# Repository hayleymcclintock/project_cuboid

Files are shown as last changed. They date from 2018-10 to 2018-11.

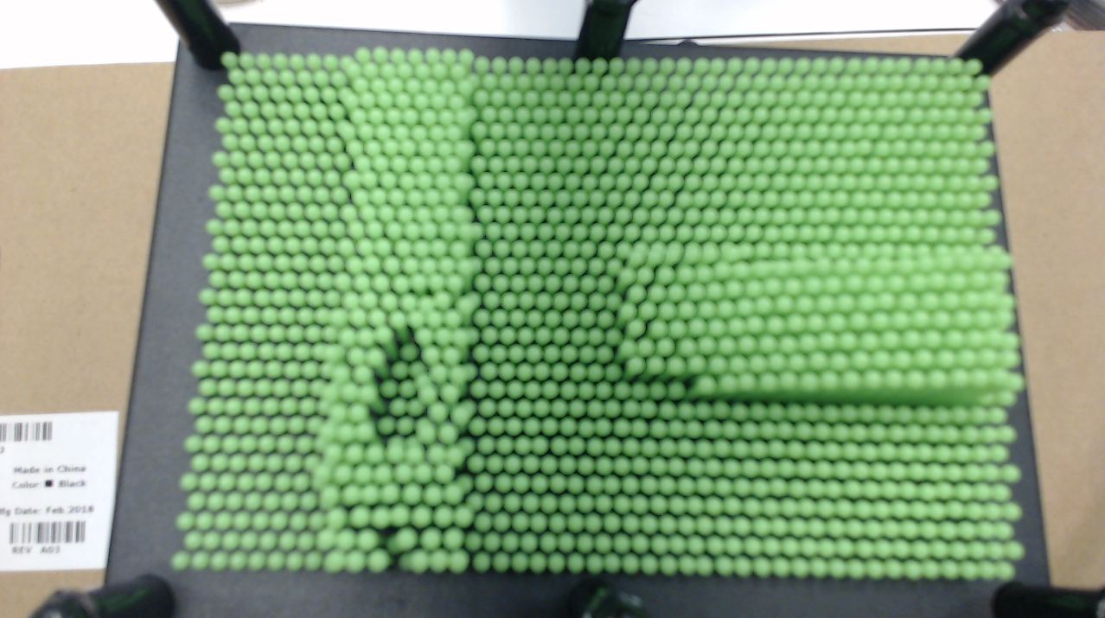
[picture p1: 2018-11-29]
Supplements/Presentations/1 First Checkin/Selection_001.png

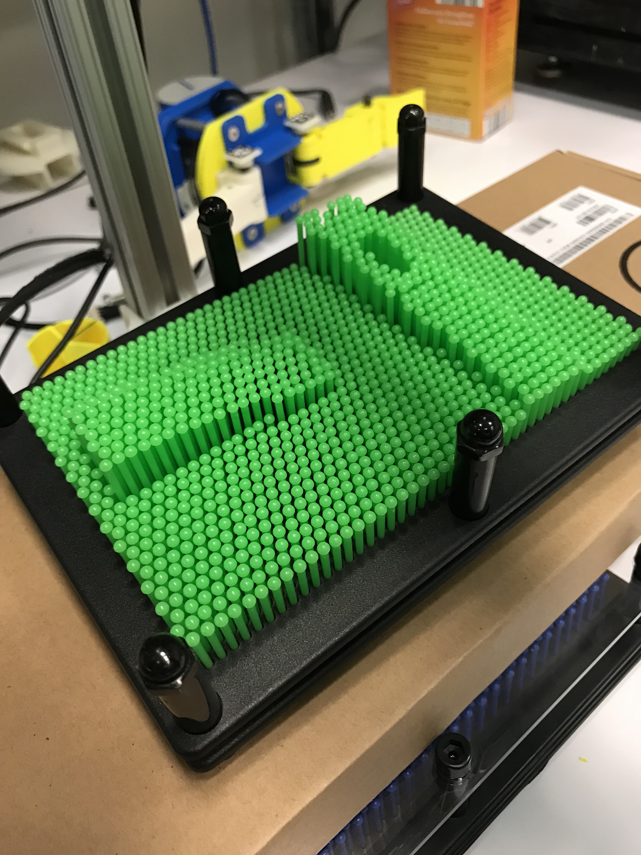
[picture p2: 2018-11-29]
Supplements/Presentations/1 First Checkin/ground_truth.jpg

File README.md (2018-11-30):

# PROJECT CUBOID
This repository contains the code and supplements to the cuboid locomoting and mapping robot for Intelligent Robotics Lab. In this repo, you will find the ROS code, paper, presentations, and data. In the following sections, we will talk about how you can get started with this project!

### Contributors
Andrew Morgan  
Robert Baines  
Hayley McClintock  

## System Requirements 
The code for this repository was mostly developed with/for ROS Kinetic (Ubuntu 16.04), with Python 2.7. OpenCV version 3.3.1-dev provides a stable bridge from OpenCV2 to OpenCV3, and was used for vision processing in this environment. If you try to run this package and have errors, please ensure you have a similar version. An Arduino Mega 256 microcontroller was utilized to control locomotion bladders and LED sequences. This communication was performed in Python and is fairly trivial with the pyserial interface. Please note that the Arduino code utilized is located within the ROS `hardware_coms` package, and is specific to the setup of this cuboid. LED addressing will need adjusted according to your specific unit.   

## ROS Packages
This section serves to introduce the reader to the packages involved in the ROS workspace. In general,the main packages are as follows:
### Vision Processor
This package takes in an image from the USB cam `topic: /camera/image_raw` and processes it accordingly. It will then publish the result according to desired block resolutions determined inside of the file (since we did not change this much, we stuck with 40 rows and 50 columns = 2000 data points).  

### USB Camera
Standard ROS camera package for working with and publishing an image from a webcam. Our main interest in this package is the use of  the`/camera/image_raw` published image. This is an open package for ROS that many people use. It is important to note that your camera does limit the resolution of this node. For the cameras used in this project, we were restricted to a `640 x 480` image, where typically you will work with 720p or 1080p. If you are requesting too high of a resolution, you will receive a camera error that eludes to improper communication. As of ubuntu 10, all drivers should be installed on your system upon setup, so therefore you need to change you camera resolution. 

### ROS Video Recorder 
Video Recorder node used for capturing published video channels in ROS. Specific parameter files must be set, allowing for multiple  videos to be recorded at the same time. To set these files, simply change data in the associated launch file in this package. In general, you will want your output and input video to be the same resolution (the package allows for users to record multiple streams at the same time, but we do not need that feature). 

### Master Control
This package will be used as the controller for all processes and timing for our system. This node communicates with the others, in a top down approach (as presented in the paper), to coordinate actuation, take pictures given specific lighting condiitions, and create the final map. You must run this node and tell it to start. Upon starting, it will complete the following sequence:  

```python
SIDE = 1
while True:
  flipCuboid()
  for edge in sideEdges:
    lightUpSequence(Edge)
    s = takePicture()
    out = processData(s)
    save(out)
  SIDE=SIDE+1
  SIDE = (SIDE-1)%4+1  #Sides are 1-4

```
## Running the Code
To get started, you will need the requirements specified in the previous section. After completing this task, you can launch the main cuboid program by:  
``roslaunch master_controller cuboid.launch``
After the system is up and running, you will need to enable movement and data collection by calling the roservice:  
``rosservice call /master_controller/enable_collection "data= true"``  
  
A useful tool for debugging is by running:  
`roslaunch hardware_coms hardware_coms_std.launch`  
This will allow you to interract with the arduino and send individual commands to the cuboid (turn on/off lights, inflate/deflate bladders). Please follow the integer values specifies in `ROS_ws/src/hardware_coms/Arduino Code/Arduino Communication.xlsx`. For example, if you wanted to inflate the bladders for the third face,  
``rosservice call /hardware_coms/do_something "data=3"``  
or if you would like to light up edge 3 of the second face,  
``rosservice call /hardware_coms/do_something "data=23"``  

## Contributions  

### Robert Baines  

### Hayley McClintock  

### Andrew Morgan
In this work, Andy was responsible for all ROS programming of the cuboid, of which is provided in the catkin workspace. This work has been sufficiently documented inside of the files so that others can properly understand and recreate this project. In addition to this duty, Andy worked on properly calibrating the camera and ensuring the vision extraction algorithm was sufficient for the shapes by shades approach. This included spec'ing a camera, calibrating the LEDs with different colors/sequences, and installing this on the cuboid.

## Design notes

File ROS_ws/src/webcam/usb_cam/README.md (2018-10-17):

usb_cam 
=======

#### A ROS Driver for V4L USB Cameras
This package is based off of V4L devices specifically instead of just UVC.

For full documentation, see [the ROS wiki](http://ros.org/wiki/usb_cam).

[Doxygen](http://docs.ros.org/indigo/api/usb_cam/html/) files can be found on the ROS wiki.

### License
usb_cam is released with a BSD license. For full terms and conditions, see the [LICENSE](LICENSE) file.

### Authors
See the [AUTHORS](AUTHORS.md) file for a full list of contributors.

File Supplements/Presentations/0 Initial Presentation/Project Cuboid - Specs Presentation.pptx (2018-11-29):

## Project Cuboid

Robert Baines, Andrew Morgan, Hayley McClintock

## Problem Statement

A cuboid with a dynamic contact surface for adaptable motion and topographic mapping on variable terrains.

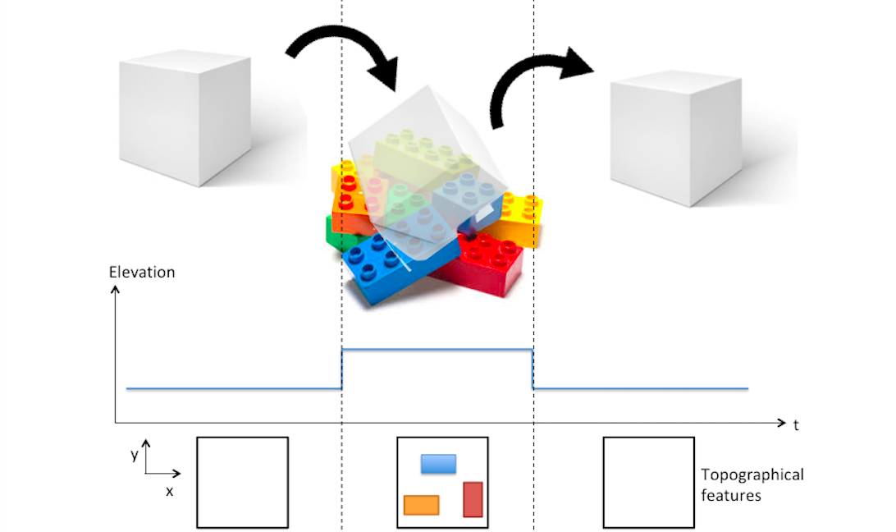
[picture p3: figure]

## Approach

- Construct a cube where 4 faces contain an array of solenoids (or other actuators)
  - Solenoids actuate the cube and serve as sensing elements
- Soft skin wrapped around the outside to prevent debris from interfering with solenoids in addition to providing better surface for rolling
- Incorporation of pressure sensors elastically coupled to solenoids for mapping the environment

## Evaluation

- Cuboid will “roll” over an obstacle course
  - Make a topographical map based on sensor feedback
  - Successfully overcome various elevation obstacles
  - Obstacles may include but are not limited to:
    - Legos
    - Office supplies (pens,paperclips, etc.)
- Quality metrics:
  - Euclidean error based on ground truth

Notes: Interesting to see the resolution we can get out of the pressure sensors

## Deliverables

- 10/12
  - Order initial testing components
  - CAD model and design
  - Electronic architecture diagram
  - Complete solenoid testing
- 11/2
  - Prototype I constructed
  - Sensor calibration
  - Testing plan
- 12/3
  - Final cube finished
  - Achieve topographical mapping
  - Locomote over obstacle course

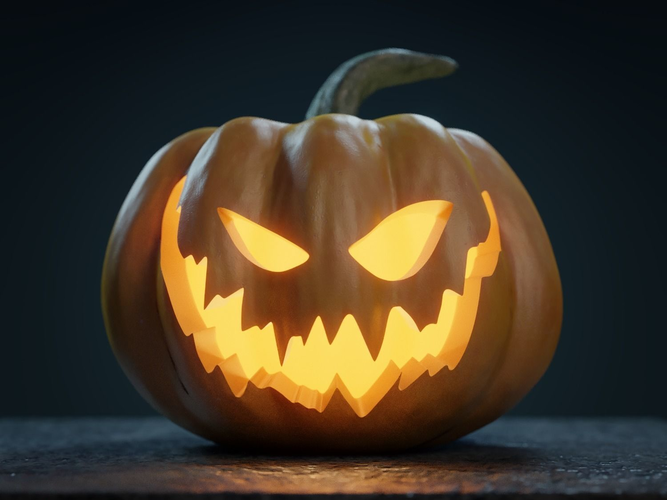
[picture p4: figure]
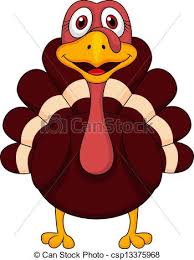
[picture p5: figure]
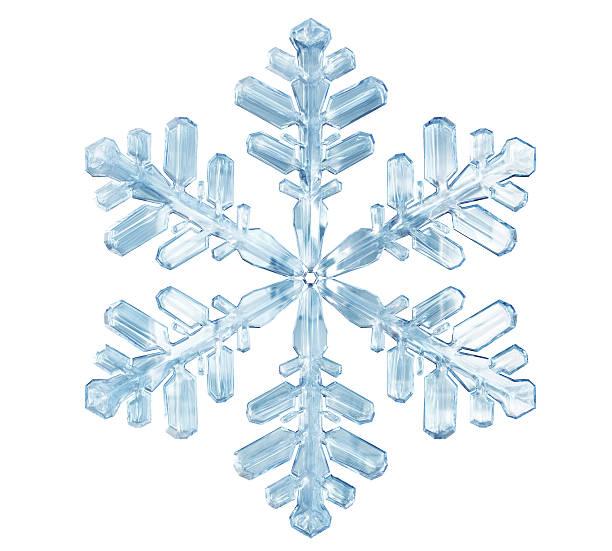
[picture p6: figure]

## Resources

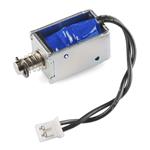
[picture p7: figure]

- Solenoids (20 at $7.99 each)
- Arduino or other microcontroller with peripherals
  - Megan 2560 for required number of inputs
- Relay arrays (25 at $2 each)
  - Reduction to 5 if desired
- IMU ($20)
  - Prior calibration required
  - Key component to sensing acceleration based on actuation input
- Pressure sensors (25 at $8 each)

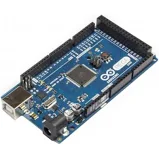
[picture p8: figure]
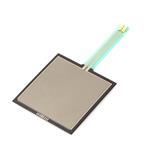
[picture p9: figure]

## Cubes in the literature

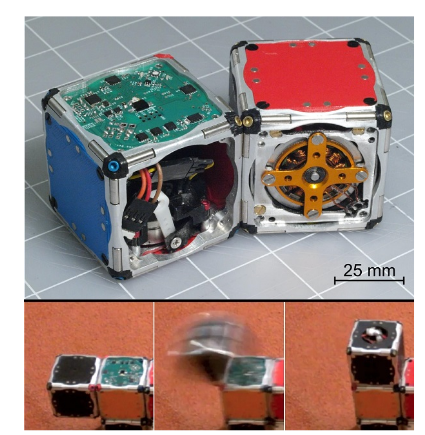
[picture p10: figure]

[Romanishin et al.]

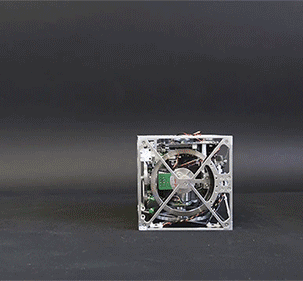
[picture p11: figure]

[Gajamohan et al.]

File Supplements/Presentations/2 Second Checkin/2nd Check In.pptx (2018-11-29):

## Project Cuboid

Robert Baines, Andrew Morgan, Hayley McClintock

## Problem Statement

A cuboid with a dynamic contact surface for adaptable motion and topographic mapping on variable terrains.


## Deliverables

- 10/12
  - Order initial testing components
  - CAD model and design
  - Electronic architecture diagram
  - Complete solenoid testing
- 11/2
  - Prototype I constructed
  - Sensor calibration
  - Testing plan
- 12/3
  - Final cube finished
  - Achieve topographical mapping
  - Locomote over obstacle course


## What we have done

- Prototype I in progress (show it)
- ROS master architecture done (show it next slide)
  - Catkin_ws: https://github.com/asmorgan24/project_cuboid
- Vision detection algorithm done
- Figured out appropriate lighting geometry for shapes by shades
  - Symmetric on/off average of 4 sides of square
- Arduino pressure regulator test code working
  - Bang bang controller ros node in progress
- Testing plan:
  - Fixed obstacle course on table top: measured object heights and dimensions
  - Evaluation metric: average mean squared error for each “plot” measurement over course
- IEEE format Manuscript started

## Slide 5

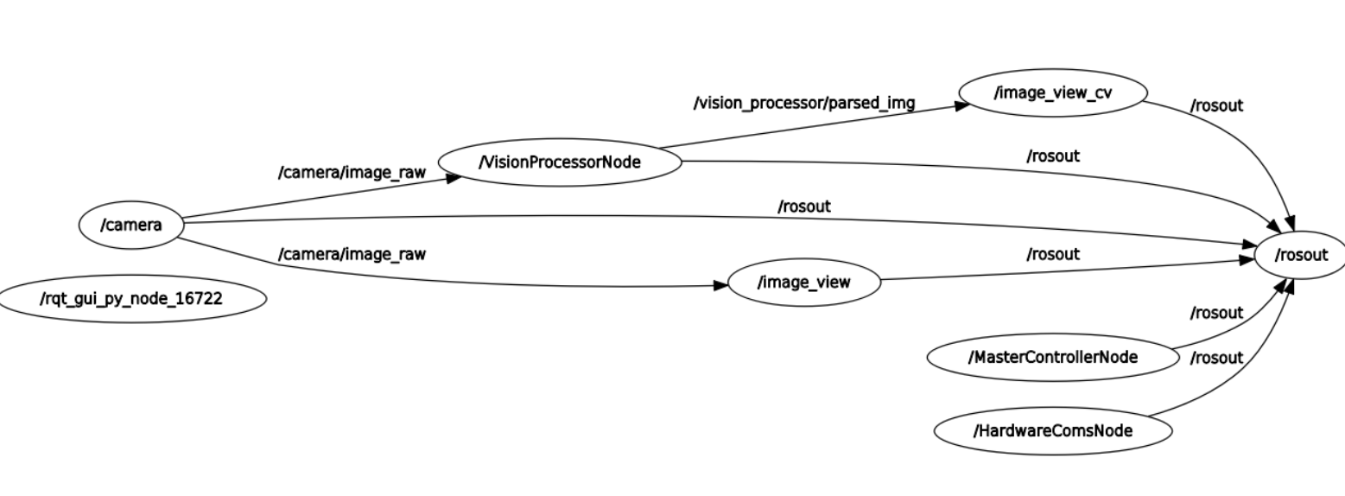
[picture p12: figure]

## Problems

- Rolling the cube
  - Inflate balloon bends in the wrong direction under the weight of the cube
  - Pins seem to inhibit motion
- Pins on pin art toy are poor quality
- We anticipate on running into larger problems with the full prototype

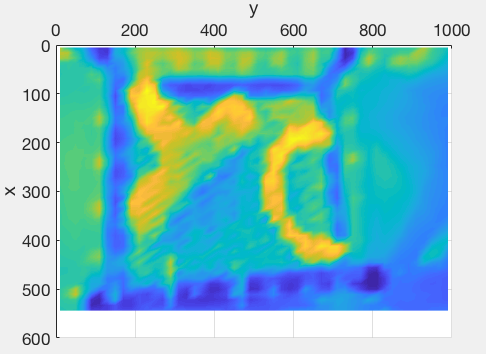
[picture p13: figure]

LED array appears in
Field of view. Easy fix via crop

## Next steps

- Get actuation working
- Finish a full prototype
- Test cameras and lighting
- Prototype camera mounting system
- Create wiki page and start populating
  - Where do we make a wiki page?

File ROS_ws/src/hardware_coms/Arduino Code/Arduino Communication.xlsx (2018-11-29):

 | Serial ASCII byte out from ROS |  | Arduino Example
Pressures | ON | OFF | https://www.arduino.cc/en/Tutorial/SerialEvent
1 | 1 | 5
2 | 2 | 6
3 | 3 | 7
4 | 4 | 8
LED Lights
Side 1
1 | 11 | 15
2 | 12 | 16
3 | 13 | 17
4 | 14 | 18
Side 2
1 | 21 | 25
2 | 22 | 26
3 | 23 | 27
4 | 24 | 28
Side 3
1 | 31 | 35
2 | 32 | 36
3 | 33 | 37
4 | 34 | 38
Side 4
1 | 41 | 45
2 | 42 | 46
3 | 43 | 47
4 | 44 | 48

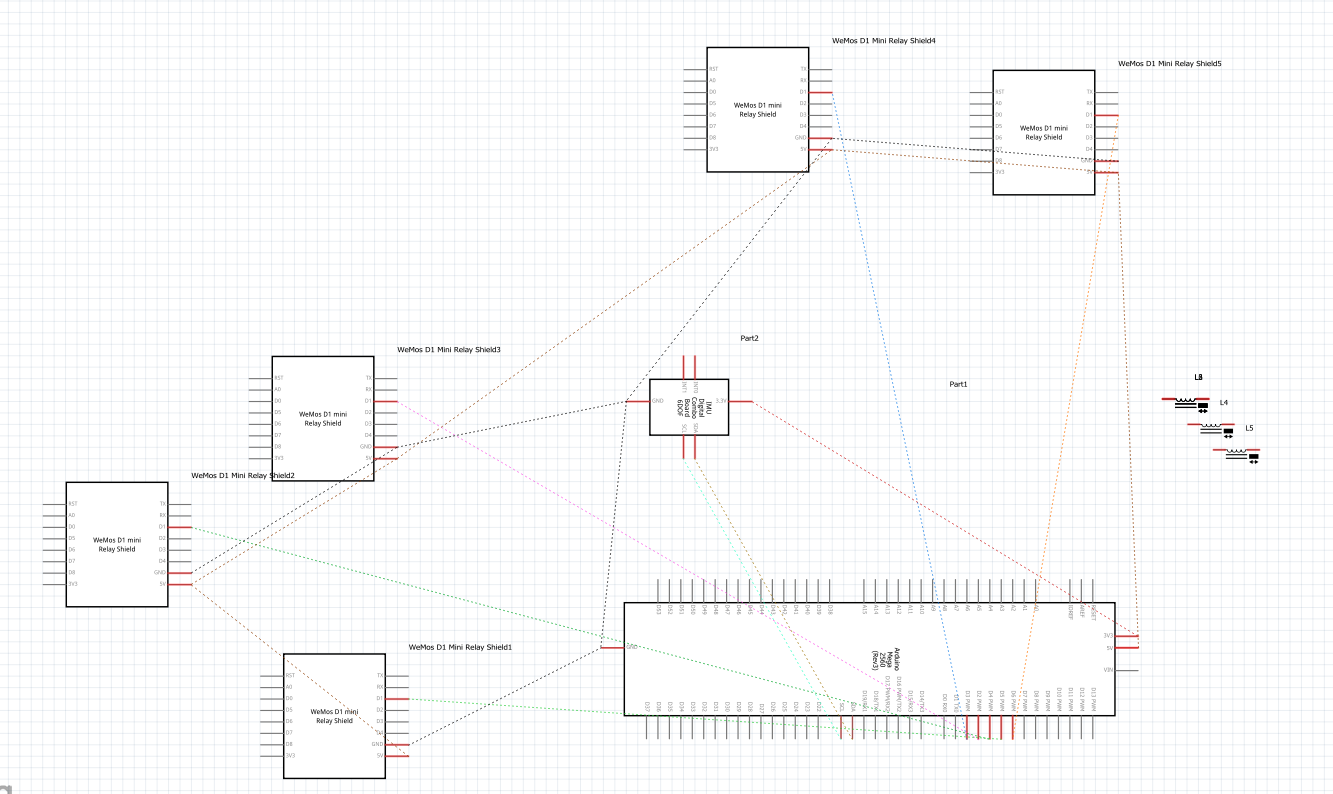
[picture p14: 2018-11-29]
Supplements/Presentations/2 Second Checkin/Initial Schematic/v1_schem.PNG

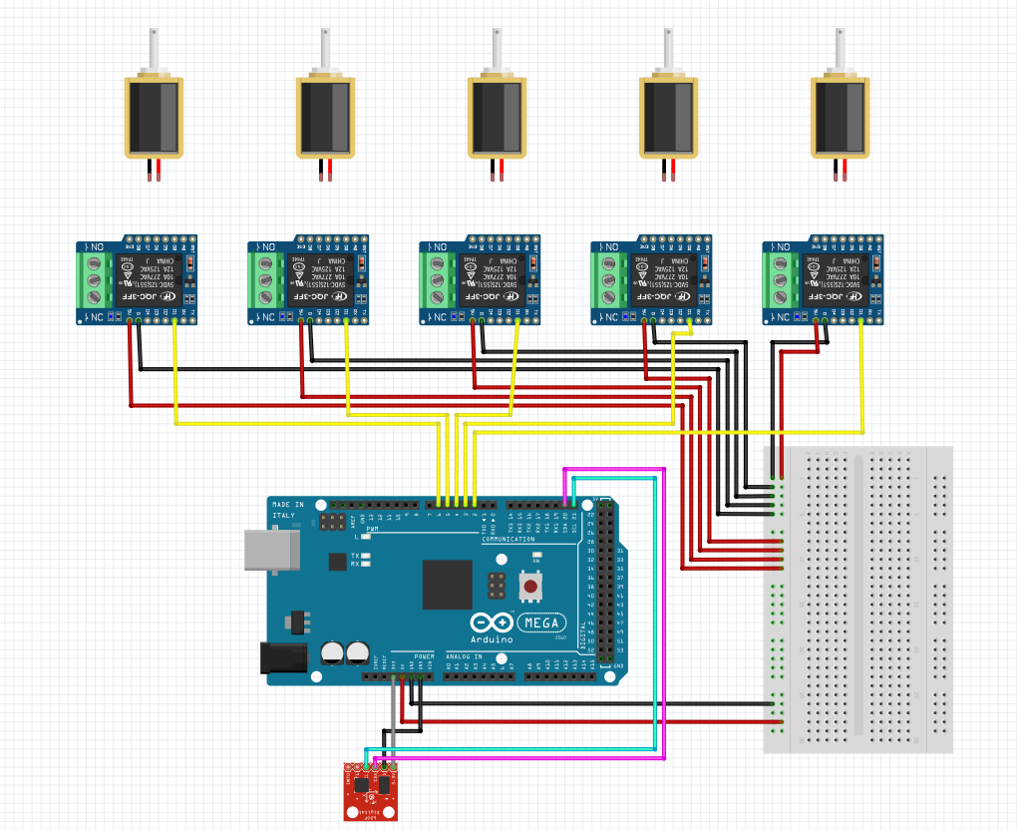
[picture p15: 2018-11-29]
Supplements/Presentations/2 Second Checkin/Initial Schematic/v1.PNG

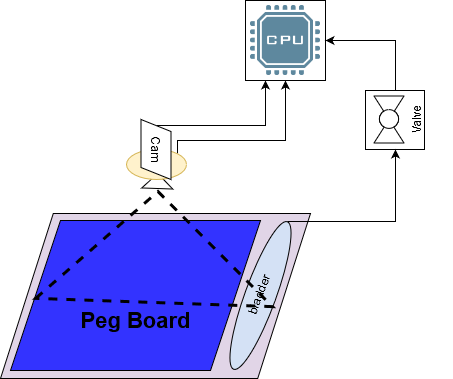
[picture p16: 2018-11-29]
Supplements/Presentations/2 Second Checkin/3 Deliverable 1 Schematic/Diagram1.png

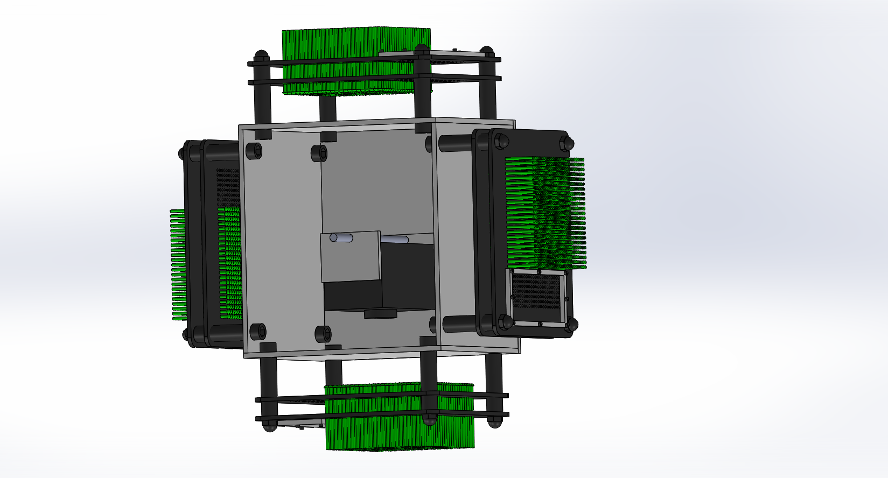
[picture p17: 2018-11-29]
Supplements/Presentations/1 First Checkin/cuboid.png

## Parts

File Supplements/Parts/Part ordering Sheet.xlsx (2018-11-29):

COMPLETED ORDERS
Item | Cost | URL | Quantity | Why | Total
Resistive pressure sensor | 9.95 | https://www.mouser.com/ProductDetail/SparkFun/SEN-09376?qs=WyAARYrbSnZm3k2OB4XwnA%3D%3D | 2 | test | 19.9
velostat conductive sheet | 3.95 | https://www.adafruit.com/product/1361?gclid=EAIaIQobChMIh9S61vPY3QIVmFYNCh0UEQNpEAQYAyABEgJq2vD_BwE | 3 | test | 11.85
5v mico solenoid | 7.99 | https://www.amazon.com/Electromagnet-Solenoid-Spring-Cabinet-Special/dp/B075H5WDD1?s=industrial | 3 | test | 23.97
5v mini push solenoid | 4.95 | https://www.adafruit.com/product/2776 | 3 | test | 14.85
bigger solidenoid | 12.93 | https://www.amazon.com/Uxcell-a14032200ux0084-Electric-Electromagnet-Solenoid/dp/B00LBQ229Y | 2 | test solenodi | 25.86
IMU | 4.39 | https://www.amazon.com/MPU-6050-MPU6050-Accelerometer-Gyroscope-Converter/dp/B008BOPN40 | 1 | test | 4.39
IMU | 8.49 | https://www.amazon.com/HiLetgo-Gyroscope-Acceleration-Accelerator-Magnetometer/dp/B01I1J0Z7Y | 1 | test | 8.49
pin art toy | 6.99 | https://www.amazon.com/Adorox-Plastic-Novelty-Multiple-Colors/dp/B00P6S4W0U?s=toys-and-games | 1 | sensor probe test | 6.99
pin art toy 2 | 10.99 | https://www.amazon.com/ScienceGeek-Plastic-Sculpture-Novelty-Green/dp/B01HBH4GTK | 1 | sensor probe test | 10.99 | TOTAL SPENT | $263.78
pin art toy 3 | 12.69 | https://www.amazon.com/LifeEase-Imagination-Challenge-Innovative-Instant-Changing/dp/B07BRS6KCM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 | 1 | sensor probe test | 12.69
4x5'' pin art toy, green | 8.99 | https://www.amazon.com/gp/product/B00S8LME9I | 1 | cause | 8.99 |  |  |  |  | 10/2/18: spring parts order
4x5'' pin art toy, blue | 5.1 | https://www.amazon.com/Shape-Child-Educational-Novelty-Table/dp/B01BFVNHVG?s=Toys+%26+Games | 1 | cause | 5.1
4x5'' pin art toy, red | 7.99 | https://www.amazon.com/Adorox-Plastic-Novelty-Multiple-Colors/dp/B0743MC8WK | 1 | cause | 7.99 |  |  |  |  | spring (k = 7 lbs./in.) | 4.85 | https://www.mcmaster.com/9434K25 | 1 | test | 4.85
3.5''x5'' metal pin art toy | $8.09 | https://www.amazon.com/Toysmith-Black-Frame-3-75-Inch-5-Inch/dp/B000FN2FI2 | 1 | test metal pins | $8.09 |  |  |  |  | spring (k = 1.1 lbs./in.) | 6.28 | https://www.mcmaster.com/9657K412 | 1 | test | 6.28
12V led white strip | $7.99 | https://www.amazon.com/Flexible-Daylight-Kitchen-Christmas-Non-waterproof/dp/B00HSF65MC | 1 | test leds | $7.99 |  |  |  |  | spring (k = 5 lbs./in.) | 4.85 | https://www.mcmaster.com/9434K38 | 1 | test | 4.85
LED assortment | $9.99 | https://www.amazon.com/Lights-Emitting-Assortment-Arduino-300-Pack/dp/B00UWBJM0Q | 1 | test leds | $9.99 |  |  |  |  | spring (k = 3 lbs./in.) | 4.98 | https://www.mcmaster.com/9434K53 | 1 | test | 4.98
RGB Led | $8.96 | https://www.amazon.com/Tricolor-Multicolor-Lighting-Electronics-Components/dp/B01C19ENDM | 1 | test leds | $8.96 |  |  |  |  | spring (k = 4.5lb/in) | 4.85 | https://www.mcmaster.com/9434K52
16ft white led strip | $1.66 | https://www.amazon.com/Radiance-Flexible-Daylight-Cuttable-Linkable/dp/B01J0WD7M6 | 1 | test leds | $1.66 |  |  |  |  | spring (k = 5 lbs./in.) | 4.85 | https://www.mcmaster.com/9434K163
addressable LED | $26.95 | https://www.amazon.com/NooElec-Addressable-Waterproof-Connectors-Pre-Soldered/dp/B008F05N54 | 1 | addressable LEd | $26.95
120 degree webcam | 29.99 | https://www.amazon.com/ELP-megapixel-Camera-Module-120degree/dp/B01DRJXDEA | 1 | Vision | 29.99
addressable LED | $26.95 | https://www.amazon.com/NooElec-Addressable-Waterproof-Connectors-Pre-Soldered/dp/B008F05N54 | 4 | addressable LEd
 | total
 | 255.69
PENDING ORDERS
Item | Cost | URL | Quantity | Why | Total
pin art toy 3 | 12.69 | https://www.amazon.com/LifeEase-Imagination-Challenge-Innovative-Instant-Changing/dp/B07BRS6KCM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 | 2 | extra pins | 25.38
Magnetic tape | 14.99 | https://www.amazon.com/Gimars-Anisotropic-Strong-Magnetic-Adhesive/dp/B07C3MQ86M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 | 1 | mounting | 14.99
 |  |  |  |  |  |  | 90 degree webcam | 48 | https://www.amazon.com/Spinel-Non-distortion-1920x1080-Adjustable-UC20MPB_ND/dp/B07143BJ6J | 1 | Vision | 48

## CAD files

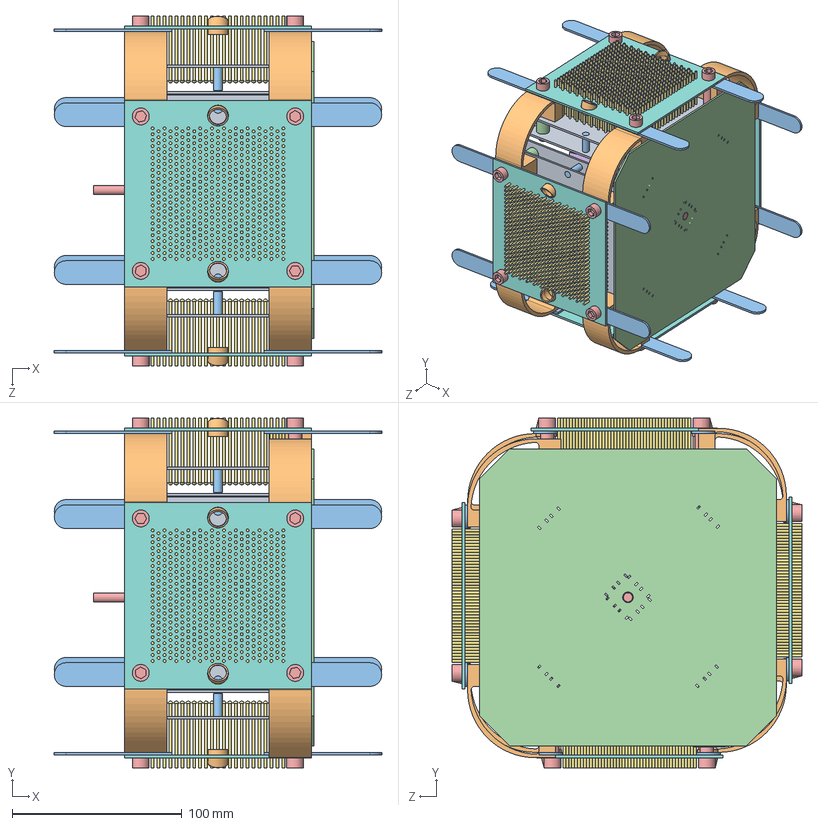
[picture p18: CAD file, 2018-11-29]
Supplements/Parts/CAD/total_assem.SLDASM
193.0 x 206.2 x 206.2 mm
top plate x 4
bracket x 8
popsicle stick x 16
spacer x 16
thick pin x 16
spacer cap x 16
thin pin x 2072
balloon side x 4
led side x 4
director x 8
dowel x 16
trimmed side
long_dowel
cuboid_camera

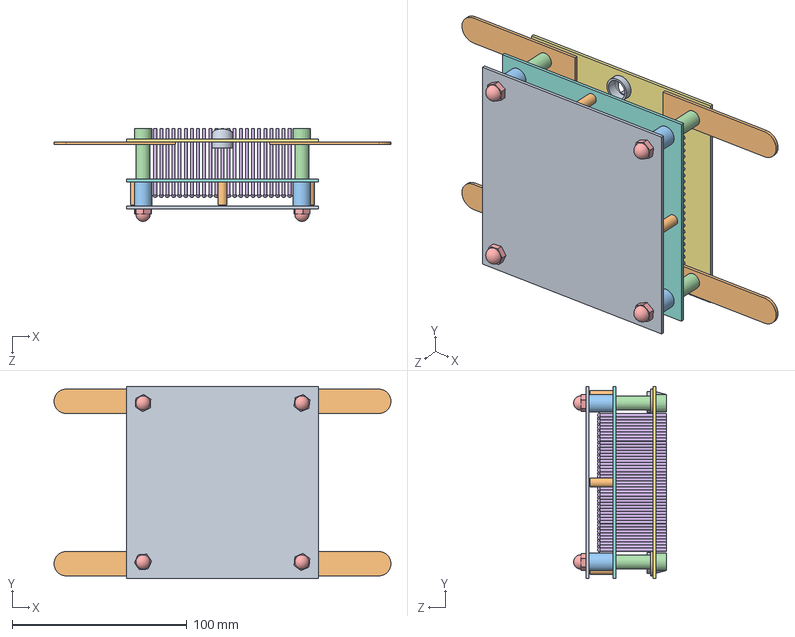
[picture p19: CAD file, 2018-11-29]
Supplements/Parts/CAD/Assem1_no_brackets.SLDASM
193.0 x 110.0 x 53.2 mm
top plate
popsicle stick x 4
spacer x 4
thick pin x 4
spacer cap x 4
thin pin x 518
balloon side
led side
director x 2
dowel x 4

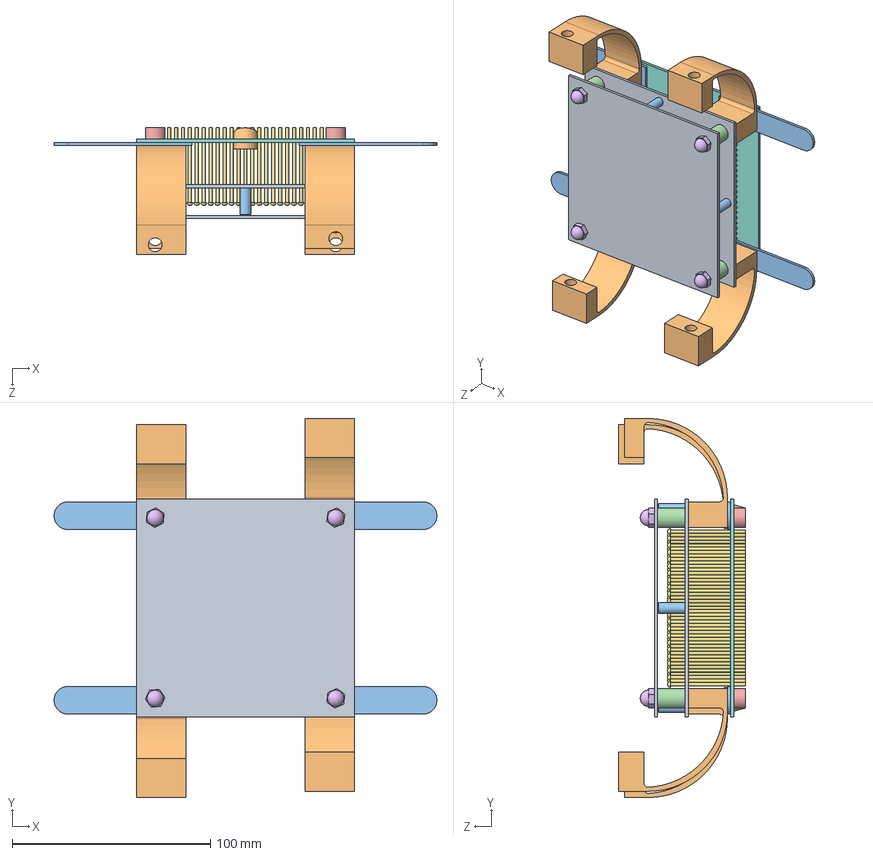
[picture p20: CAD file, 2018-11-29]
Supplements/Parts/CAD/Assem1.SLDASM
193.0 x 191.0 x 64.2 mm
top plate
bracket x 4
popsicle stick x 4
spacer x 4
thick pin x 4
spacer cap x 4
thin pin x 518
balloon side
led side
director x 2
dowel x 4

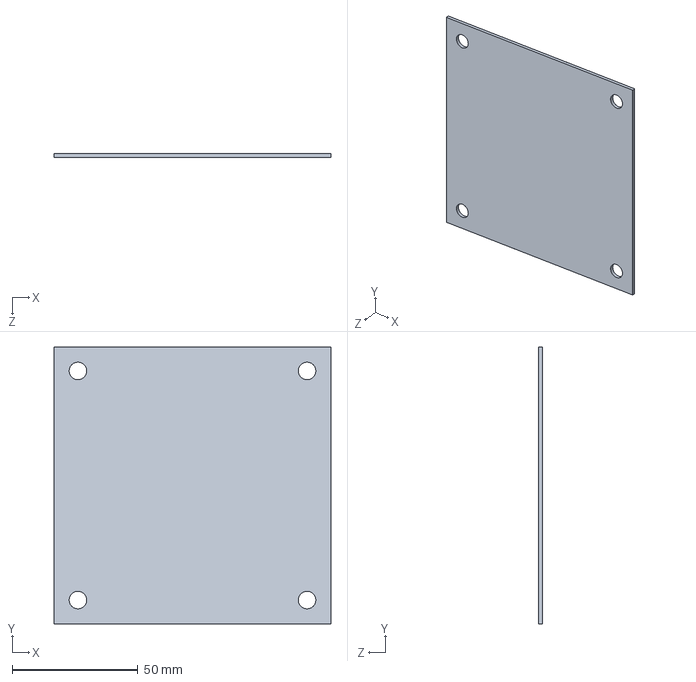
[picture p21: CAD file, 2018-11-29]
Supplements/Parts/CAD/top plate.SLDPRT
110.0 x 110.0 x 1.59 mm

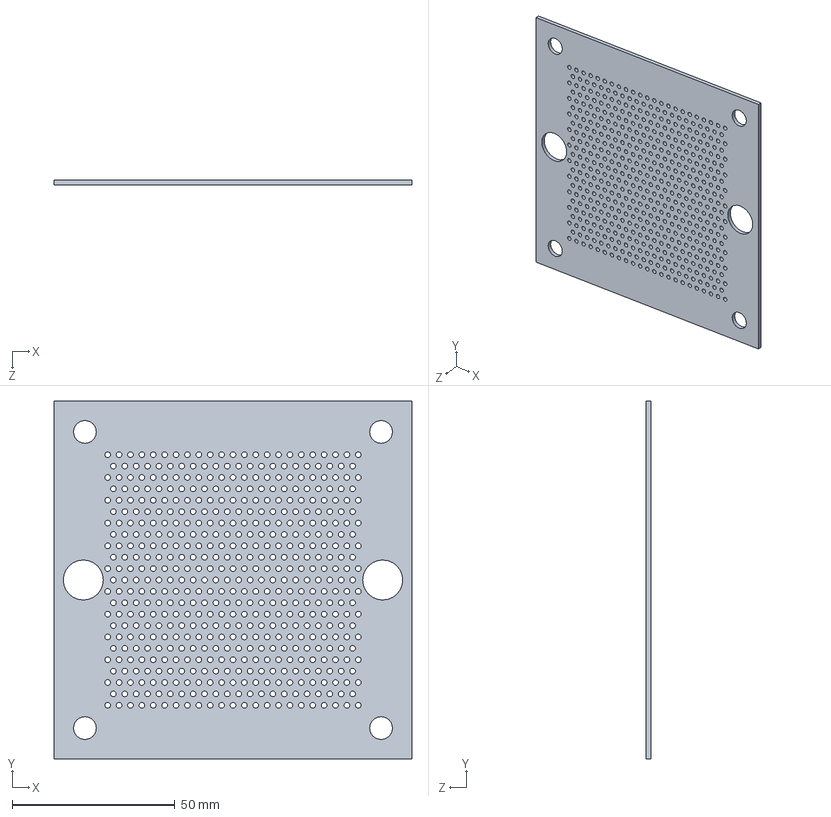
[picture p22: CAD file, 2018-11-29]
Supplements/Parts/CAD/balloon side.SLDPRT
110.0 x 110.0 x 1.59 mm

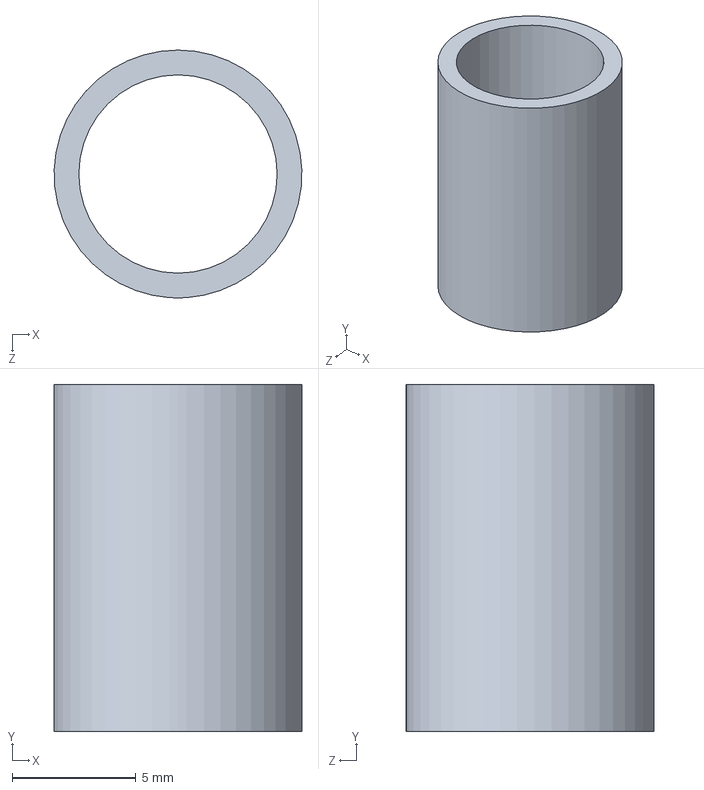
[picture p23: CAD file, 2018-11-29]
Supplements/Parts/CAD/spacer.SLDPRT
9.99 x 14.0 x 10.0 mm

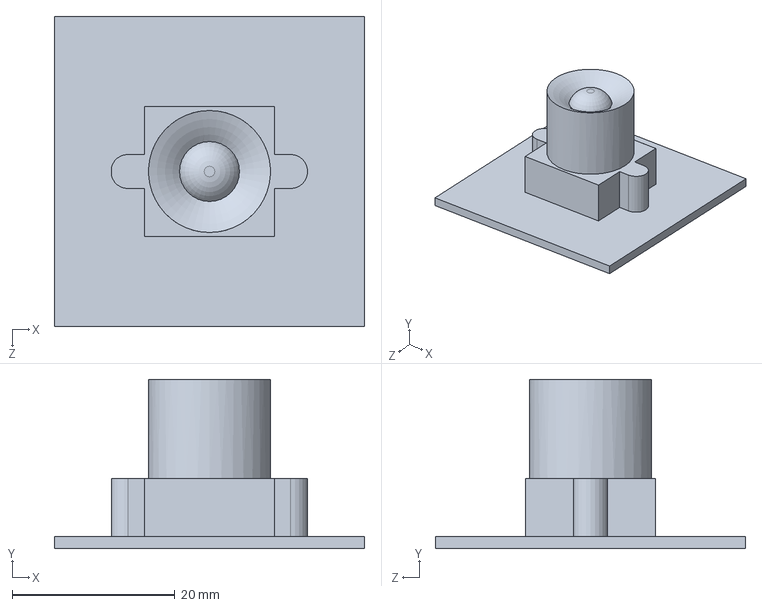
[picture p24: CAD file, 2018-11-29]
Supplements/Parts/CAD/cuboid_camera.SLDPRT
38.1 x 20.8 x 38.1 mm

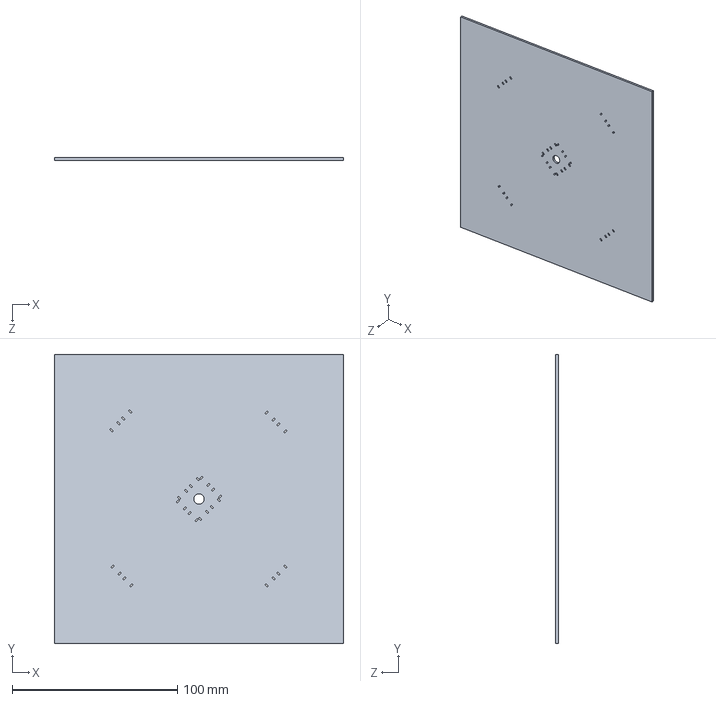
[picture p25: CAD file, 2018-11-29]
Supplements/Parts/CAD/side.SLDPRT
175.0 x 175.0 x 1.59 mm

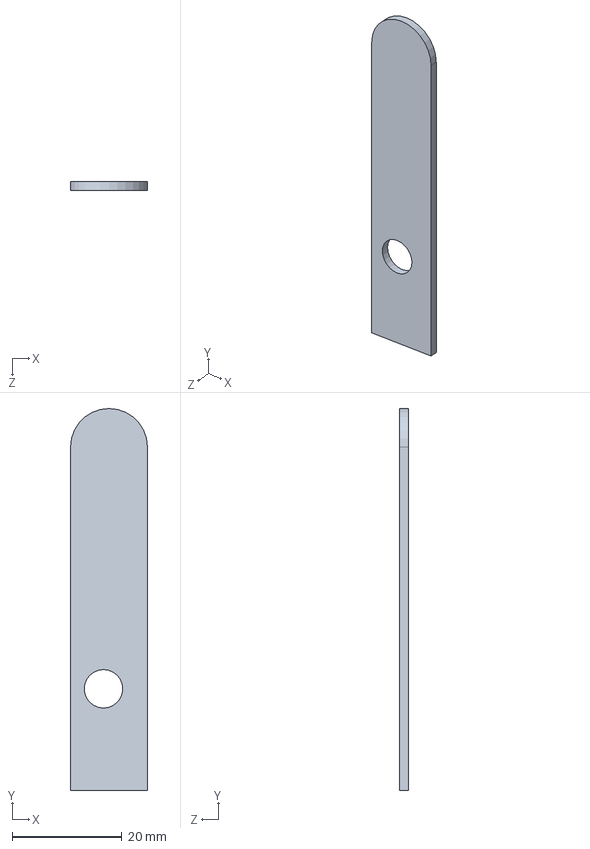
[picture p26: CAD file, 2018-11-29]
Supplements/Parts/CAD/popsicle stick.SLDPRT
14.0 x 69.5 x 1.59 mm

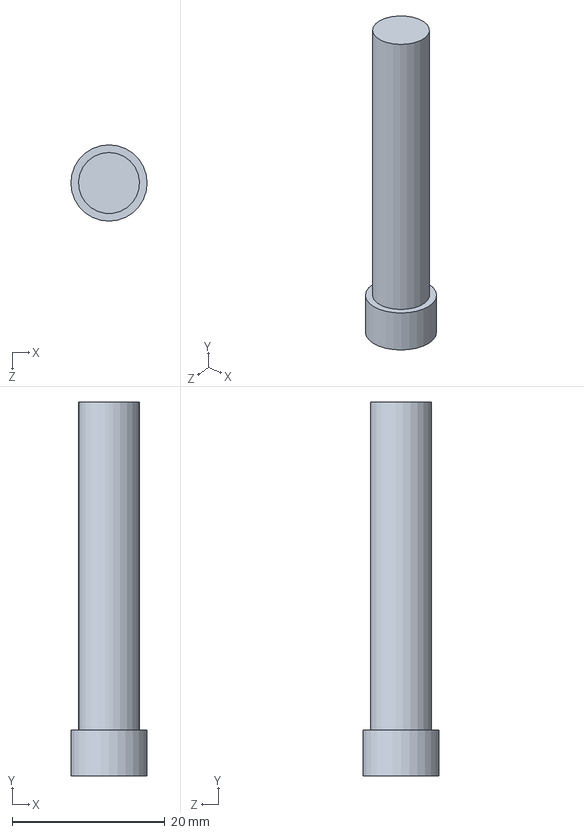
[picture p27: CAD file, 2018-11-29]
Supplements/Parts/CAD/thick pin.SLDPRT
10.0 x 49.0 x 10.0 mm

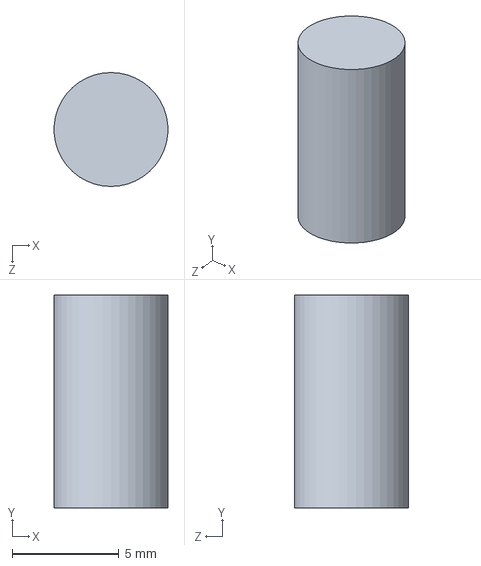
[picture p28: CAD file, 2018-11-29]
Supplements/Parts/CAD/peg.SLDPRT
5.34 x 10.0 x 5.35 mm

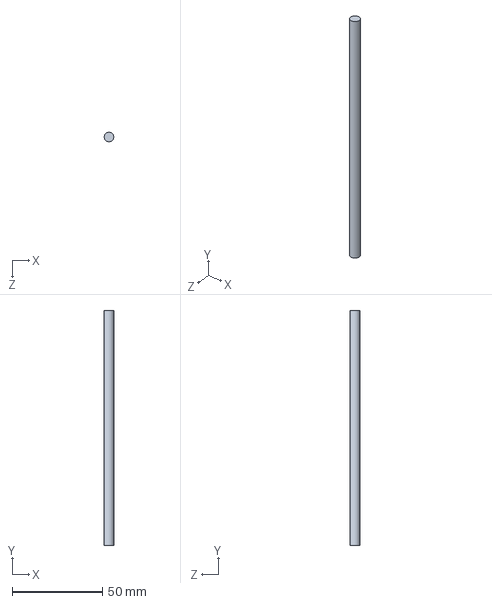
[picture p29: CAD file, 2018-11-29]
Supplements/Parts/CAD/long_dowel.SLDPRT
5.35 x 130.0 x 5.35 mm

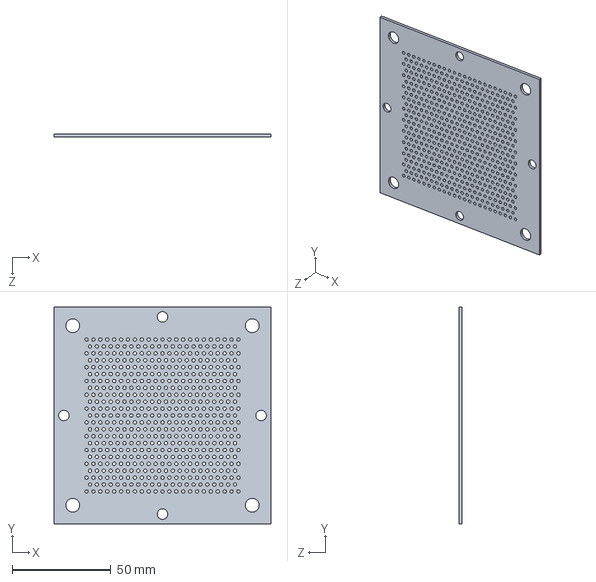
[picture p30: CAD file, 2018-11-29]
Supplements/Parts/CAD/led side.SLDPRT
110.0 x 110.0 x 1.59 mm

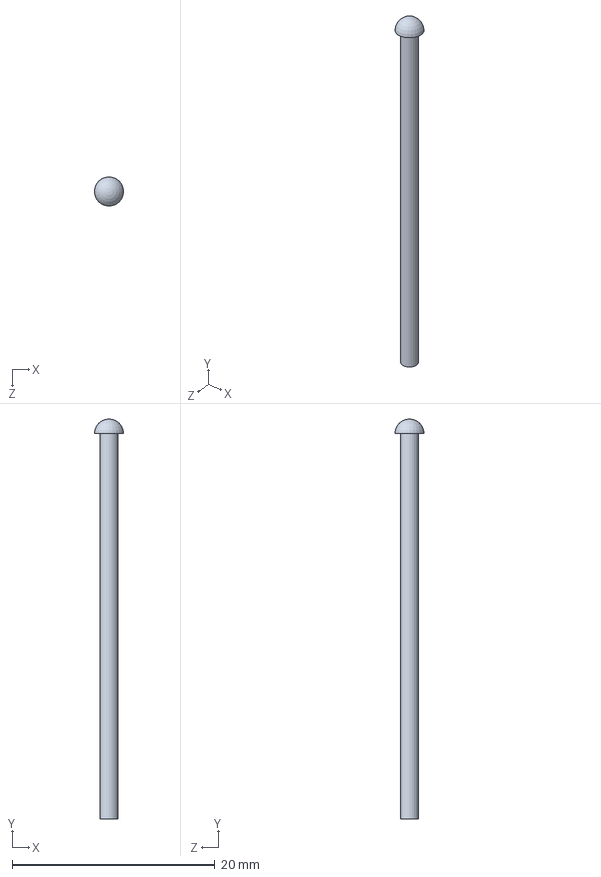
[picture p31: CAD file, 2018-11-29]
Supplements/Parts/CAD/thin pin.SLDPRT
2.88 x 39.4 x 2.88 mm

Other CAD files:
Supplements/Parts/CAD/side2.dwg
Supplements/Parts/CAD/sides.dwg
Supplements/Parts/CAD/custom pin toy 3.dwg
Supplements/Parts/CAD/bracket.SLDPRT
Supplements/Parts/CAD/camera_mount.SLDPRT
Supplements/Parts/CAD/director.SLDPRT
Supplements/Parts/CAD/dowel.SLDPRT
Supplements/Parts/CAD/popsicle stick.dwg
Supplements/Parts/CAD/spacer cap.SLDPRT
Supplements/Parts/CAD/spacer2.SLDPRT
Supplements/Parts/CAD/trimmed side.SLDPRT

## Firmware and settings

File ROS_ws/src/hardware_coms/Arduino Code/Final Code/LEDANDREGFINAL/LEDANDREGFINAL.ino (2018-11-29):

// master Arduino code with pressure regulator and LED utility. Waits for ROS controller to send it a char via serial, and then executes an action
// accoridng to that Char.
// coding in progress. Last edit: 11/12/18 at 3:32 pm : debugged in arduino IDE compiler. Have yet to test.

#include "FastLED.h" // library for LEDs 
// for the LEDs: D6 yellow  , D7  green, Orange Power Supply +5V , Black Power Supply GND, make sure to connect this and arduino GND
#include <math.h>
#include <Wire.h> // for I2C pressure reg 
//  for the pressure reg:  SLC 21 green, SLA 20 blue, black GND, red 5V



//LED CONFIGURATION  ---------------------------------------------------------------------
// how much power are we going to draw? we have 30 led/meter. and 1 meter.
// putting power supply at 5v 1.5 a should be more than sufficient!

// How many leds in your strip?
#define NUM_LEDS 120 // this will change once we string together the 4 strips and cut it... 
#define DATA_PIN 6
#define CLOCK_PIN 7
CRGB leds[NUM_LEDS]; // set up block of memory used for storing and manipulating LED data

//-----------------------------------------------------------------------------------------


//
//// P_REG CONFIGURATION  -------------------------------------------------------------------
// System configuration variables
const int NUM_ACTUATORS = 8; // **USER**
int pressureRegulatorAddresses[NUM_ACTUATORS] = {59,60,61,72, 73, 79, 80, 81}; // these are actuators 0, 1, 2 and 3 **USER**

// Memory Addresses
const int INDEX_SETPOINT_HIGH_BYTE = 16; // Default setpoint is atmospheric pressure (-0.147 [PSI])
const int INDEX_DESIRED_STATE = 18; // State. 0 = Release, 1 = Hold, 2 = Inflate. Our desired state. This is only active during manual mode.  Default valve state is hold (both valves off).
const int INDEX_PRESSURE_SENSOR_HIGH_BYTE = 19; //High byte of our actuator's pressure sensor
const int INDEX_HALF_BAND = 21; //  1/2*How wide our bang-bang deadband should be. Default Half-band is 10 [ADC values] = 2.94 [PSI]
const int INDEX_OPERATION_MODE = 22; // What mode should we operate in? automatic = 0. manual = 1. Default mode is manual
const int INDEX_ONLY_SEND_PRESSURE = 23; // If == 0, then the i2cArray can be read. ElseIf == 1, every read results in reading pressure. Default read mode is "only send pressure"

// 1) General variables
const int nBytes = 2; // How many bytes to read
float values[NUM_ACTUATORS]; // Array of received data
float filteredValues[NUM_ACTUATORS]; // Array of filtered sensor data
int iterState = 0; // State in the iteration (used for cycling between commands)
unsigned long currentMillis = 0.0;
unsigned long commandMillis = 1000; // How long to delay between commands
unsigned long cycleMillis = 10; // How long to delay between cycles
bool changeState = false;

// 2) Pressure Regulator Variables
const int AUTOMATIC = 0;
const int MANUAL = 1; //
int controlMode = MANUAL; // **USER** // manual is PIC waits for you to tell it with arduino or whatever command to open or close. automatic: you tell it pressure, it gets there.
bool onlySendPressure = 0; // **USER**
unsigned long command = 0;
unsigned long commandToSend = 0; // Use unsigned int to make allow bitshift operator
const int halfBand = 3;
float expConst = .9; // **USER** Decay (time) constant for the (optional) exponential filter. 0.9 is rather agressive. 0 is same as no filter.
//---------------------------------------------------------------------------------------------

const int delay_on = 3000;
const int delay_off = 500;

void setup() {
  // LED SETUP --------------------------------------------------------------------------------
  FastLED.addLeds<WS2801, DATA_PIN, CLOCK_PIN, RGB>(leds, NUM_LEDS); // setup stuff for LED library
  // will have to add the other 4 leds here later...

  //-------------------------------------------------------------------------------------------

  //turn off all LED first
  turn_off_all_led();

  //   // P_REG SETUP -------------------------------------------------------------------------------
    Wire.begin();        // join i2c bus (address optional for master)
    Serial.begin(9600);  // start serial for output
  //  currentMillis = millis(); // Initial time
  //
  //  for (int actuator = 0; actuator < NUM_ACTUATORS; actuator++) {
  //    writeI2C(pressureRegulatorAddresses[actuator], INDEX_OPERATION_MODE, controlMode); // Send pic firmware mode to the actuator
  //    writeI2C(pressureRegulatorAddresses[actuator], INDEX_HALF_BAND, halfBand); // Send inHalfBand to the actuator
  //    writeI2C(pressureRegulatorAddresses[actuator], INDEX_ONLY_SEND_PRESSURE, onlySendPressure); // Send "don't only send pressure" to the actuator
  //  }
  //-------------------------------------------------------------------------------------------

}



void loop() {

  int section_size = 5; // how many lights are strung around one face of the pin toy ?

  // send data only when you receive data from ROS
  if (Serial.available() > 0) {
    // read the incoming byte:
    int incomingByte = Serial.read();
    Serial.println(incomingByte);
    //P_REG SEND COMAND SECTION---------------------------------------------------------------------
  //{59,60,61,72, 73, 79, 80, 81} are the numbers of the regs are 0 1 are face 1, 2 3 are face 2, 4 5 are face 3, 6 7 are face 4.
  
    if (incomingByte == 1) {     //pressure reg 0 and 1 ON for face 1 
      command = 2;
      writeI2C(pressureRegulatorAddresses[0], INDEX_DESIRED_STATE, command);
      delay(delay_on); 
      writeI2C(pressureRegulatorAddresses[1], INDEX_DESIRED_STATE, command);
      delay(2000);
      writeI2C(pressureRegulatorAddresses[0], INDEX_DESIRED_STATE, 0); 
    }
    else if (incomingByte == 5) { //pressure reg 0 and 1 off for face 1 
      command = 0;
      writeI2C(pressureRegulatorAddresses[0], INDEX_DESIRED_STATE, command);
      delay(delay_off); 
      writeI2C(pressureRegulatorAddresses[1], INDEX_DESIRED_STATE, command);
    }
    else if (incomingByte == 2) { //pressure reg 2 and 3 ON for face 2 
      command = 2;
      writeI2C(pressureRegulatorAddresses[2], INDEX_DESIRED_STATE, command);
      delay(2500); 
      writeI2C(pressureRegulatorAddresses[3], INDEX_DESIRED_STATE, command);
      delay(2000);
      writeI2C(pressureRegulatorAddresses[2], INDEX_DESIRED_STATE, 0); 
    }
    else if (incomingByte == 6) { //pressure reg 2 and 3 OFF for face 2
      command = 0;
      writeI2C(pressureRegulatorAddresses[2], INDEX_DESIRED_STATE, command);
      delay(delay_off); 
      writeI2C(pressureRegulatorAddresses[3], INDEX_DESIRED_STATE, command);   
      }
    else if (incomingByte == 3) { //pressure reg 4 and 5 for face 3 ON
      command = 2;
      writeI2C(pressureRegulatorAddresses[4], INDEX_DESIRED_STATE, command);
      delay(5000); 
      writeI2C(pressureRegulatorAddresses[5], INDEX_DESIRED_STATE, command);
      delay(3500);
      writeI2C(pressureRegulatorAddresses[4], INDEX_DESIRED_STATE, 0);
    }
    else if (incomingByte == 7) { //pressure reg 4 and 5 for face 3 OFF
      command = 0;
      writeI2C(pressureRegulatorAddresses[4], INDEX_DESIRED_STATE, command);
      delay(delay_off); 
      writeI2C(pressureRegulatorAddresses[5], INDEX_DESIRED_STATE, command);  
    }
    else if (incomingByte == 4) { //pressure reg 6 and 7 for face 4 ON
      command = 2;
      writeI2C(pressureRegulatorAddresses[6], INDEX_DESIRED_STATE, command);
      delay(delay_on); 
      writeI2C(pressureRegulatorAddresses[7], INDEX_DESIRED_STATE, command);
      delay(2000);
      writeI2C(pressureRegulatorAddresses[6], INDEX_DESIRED_STATE, 0); 
    }
    else if (incomingByte == 8) { //pressure reg 6 and 7 for face 4 OFF
      command = 0;
      writeI2C(pressureRegulatorAddresses[6], INDEX_DESIRED_STATE, command);
      delay(delay_off); 
      writeI2C(pressureRegulatorAddresses[7], INDEX_DESIRED_STATE, command);
    }
//    ------------------------------------------------------------------------------------------ -



    //LED SEND COMAND SECTION -------------------------------------------------------------------
    else if (incomingByte == 11) { //LED side 1 section 1 ON
      int section_size = 4;
      turn_on_led(section_size, 0);
      turn_on_led(4,33);  
      
    }
    else if (incomingByte == 15) { //LED side 1 section 1 oFF
      int section_size = 4; 
      turn_off_led(section_size, 0); 
      turn_off_led(4, 33);
    }
    else if (incomingByte == 12) { //LED side 1 section 2 ON
      int section_size = 4; 
      turn_on_led(section_size, section_size * 2 - section_size - 1);
      turn_on_led(4,37); 
    }
    else if (incomingByte == 16) { //LED side 1 section 2 oFF
      int section_size = 4; 
      turn_off_led(section_size, section_size * 2 - section_size - 1);
      turn_off_led(4,37); 
    }
    else if (incomingByte == 13) { //LED side 1 section 3 ON
      int section_size = 3; 
      turn_on_led(section_size, 8);
      turn_on_led(section_size, 8);
    }
    else if (incomingByte == 17) { //LED side 1 section 3 oFF
      int section_size = 3; 
      turn_off_led(section_size, 8);
      turn_off_led(section_size, 8);
    }
    else if (incomingByte == 14) { //LED side 1 section 4 ON
      int section_size = 4; 
      turn_on_led(section_size, section_size * 4 - section_size - 1);
      turn_on_led(3,30); 
    }
    else if (incomingByte == 18) { //LED side 1 section 4 oFF
      int section_size = 4; 
      turn_off_led(section_size, section_size * 4 - section_size - 1);
      turn_off_led(3,30); 
    }
///////////////////////////////////////////////////////////////////
    else if (incomingByte == 21) { //LED side 2 section 1 ON
      turn_on_led(section_size, section_size * 5 - section_size - 1);
      turn_on_led(4, 52);
    }
    else if (incomingByte == 25) { //LED side 2 section 1 OFF
      turn_off_led(section_size, section_size * 5 - section_size - 1);
        turn_off_led(4, 52);

    }
    else if (incomingByte == 22) { //LED side 2 section 2 ON
      turn_on_led(section_size-1, section_size * 6 - section_size - 2);
      turn_on_led(4, 49);
    }
    else if (incomingByte == 26) { //LED side 2 section 2 OFF
      turn_off_led(section_size-1, section_size * 6 - section_size - 2);
       turn_off_led(4, 49);
    }
    else if (incomingByte == 23) { //LED side 2 section 3 ON
      turn_on_led(3, section_size * 7 - section_size - 3);
      turn_on_led(3, 49- 3); 
    }
    else if (incomingByte == 27) { //LED side 2 section 3 OFF
      turn_off_led(3, section_size * 7 - section_size - 3);
      turn_off_led(3, 49 - 3); 

    }
    else if (incomingByte == 24) { //LED side 2 section 4 ON
      turn_on_led(section_size, section_size * 8 - section_size - 21);
      turn_on_led(3,57); 
    }
    else if (incomingByte == 28) { //LED side 2 section 4 oFF
      turn_off_led(section_size, section_size * 8 - section_size - 21);
      turn_off_led(3,57); 
    }

    else if (incomingByte == 31) { //LED side 3 section 1 ON
      turn_on_led(4, 30);
      turn_on_led(4, 11); 
    }
    else if (incomingByte == 35) { //LED side 3 section 1 Off
      turn_off_led(4, 30);
      turn_off_led(4, 11); 
    }
    else if (incomingByte == 32) { //LED side 3 section 2 ON
      turn_on_led(4,34);
      turn_on_led(4, 0);
    }
    else if (incomingByte == 36) { //LED side 3 section 2 Off
      turn_off_led(4,34);
      turn_off_led(4, 0);
    }
    else if (incomingByte == 33) { //LED side 3 section 3 ON
      turn_on_led(4,38);
      turn_on_led(3, 4);
    }
    else if (incomingByte == 37) { //LED side 3 section 3 Off
      turn_off_led(4,38);
      turn_off_led(3, 4);
    }
    else if (incomingByte == 34) { //LED side 3 section 4 ON
      turn_on_led(3, 42);
      turn_on_led(3,8); 
    }
    else if (incomingByte == 38) { //LED side 3 section 4 Off
      turn_off_led(3, 42);
      turn_off_led(3,8); 
    }
    else if (incomingByte == 41) { //LED side 4 section 1 ON
      turn_on_led(4,45);
      turn_on_led(4,26); 
    }
    else if (incomingByte == 45) { //LED side 4 section 1 Off
      turn_off_led(4,45);
      turn_off_led(4,26); 
    }
    else if (incomingByte == 42) { //LED side 4 section 2 ON
      turn_on_led(4,49);
      turn_on_led(3,23);
    }
    else if (incomingByte == 46) { //LED side 4 section 2 Off
      turn_off_led(4,49);
      turn_off_led(3,23);
    }
    else if (incomingByte == 43) { //LED side 4 section 3 ON
      turn_on_led(4,53);
      turn_on_led(4, 19); 
    }
    else if (incomingByte == 47) { //LED side 4 section 3 Off
      turn_off_led(4,53);
      turn_off_led(4, 19); 
    }
    else if (incomingByte == 44) { // LED side 4 section 4 ON
      turn_on_led(3, 57);
      turn_on_led(4, 15); 
    }
    else if (incomingByte == 48) { // LED side 4 section 4 off
      turn_off_led(3, 57);
      turn_off_led(4, 15); 
    }
    //----------------------------------------------------------------------
  }
}


//Helper Functions LEDs ------------------------------------------------

// turns on the led section
int turn_on_led(int inSectionSize, int firstIndSec) {

  for (int i = firstIndSec; i < inSectionSize + firstIndSec; i++) {
    leds[i] = CHSV(160, 255, 128);//CHSV(0, 10, 255); //pretty bright white (HSV Color input)
    FastLED.show();
  }
}

// turn off led section
int turn_off_led(int inSectionSize, int firstIndSec) {

  for (int i = firstIndSec; i < inSectionSize + firstIndSec; i++) {
    leds[i] = CHSV(0, 0, 0); // no color
    FastLED.show();
  }
}


//turn off all led
int turn_off_all_led() {

  for (int i = 0; i < NUM_LEDS; i++) {
    leds[i] = CHSV(0, 0, 0); //no color
    FastLED.show();
  }
}

//---------------------------------------------------------------------



//Helper function Pres_reg --------------------------------------------

void writeI2C(int inAddress, int inIndex, int inValue) {
  Wire.beginTransmission(inAddress); //Prepare internal variables
  Wire.write(inIndex);        // write memory locaiton to buffer
  Wire.write(inValue);        // write value to buffer
  Wire.endTransmission();    // transmit
}

//---------------------------------------------------------------------

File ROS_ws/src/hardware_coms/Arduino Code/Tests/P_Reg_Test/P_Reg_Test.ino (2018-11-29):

// This driver is for testing pneumatic regulator(s).
// Assumes your PIC firmware will send, in sequence, the memory located at [the most recent
// sent index] upon a read request.
// Writes state to and reads pressure from a pressure regulator.
// Typical parameters a user wants to edit are marked by **USER**

#include <Wire.h>

// System configuration variables
const int NUM_ACTUATORS = 8; // **USER**
int pressureRegulatorAddresses[NUM_ACTUATORS] = {59, 60,61,72,73,79,80,81}; // **USER**
//int pressureRegulatorAddresses[NUM_ACTUATORS] = {33}; // **USER** these are the numbers written on  the regulators (or stickers)

// Memory Addresses
const int INDEX_SETPOINT_HIGH_BYTE = 16; // Default setpoint is atmospheric pressure (-0.147 [PSI])
const int INDEX_DESIRED_STATE = 18; // State. 0 = Release, 1 = Hold, 2 = Inflate. Our desired state. This is only active during manual mode.  Default valve state is hold (both valves off).
const int INDEX_PRESSURE_SENSOR_HIGH_BYTE = 19; //High byte of our actuator's pressure sensor
const int INDEX_HALF_BAND = 21; //  1/2*How wide our bang-bang deadband should be. Default Half-band is 10 [ADC values] = 2.94 [PSI]
const int INDEX_OPERATION_MODE = 22; // What mode should we operate in? automatic = 0. manual = 1. Default mode is manual
const int INDEX_ONLY_SEND_PRESSURE = 23; // If == 0, then the i2cArray can be read. ElseIf == 1, every read results in reading pressure. Default read mode is "only send pressure"

// 1) General variables
const int nBytes = 2; // How many bytes to read
float values[NUM_ACTUATORS]; // Array of received data
float filteredValues[NUM_ACTUATORS]; // Array of filtered sensor data
int iterState = 0; // State in the iteration (used for cycling between commands)
unsigned long currentMillis = 0.0;
unsigned long commandMillis = 1000; // How long to delay between commands
unsigned long cycleMillis = 10; // How long to delay between cycles
bool changeState = false;

// 2) Pressure Regulator Variables
const int AUTOMATIC = 0;
const int MANUAL = 1; // 
int controlMode = MANUAL; // **USER**
bool onlySendPressure = 0; // **USER**
unsigned long command = 0;
unsigned long commandToSend = 0; // Use unsigned int to make allow bitshift operator
const int halfBand = 3;

float expConst = .9; // **USER** Decay (time) constant for the (optional) exponential filte    0.9 is rather agressive. 0 is same as no filter. r

void setup() {
  Wire.begin();        // join i2c bus (address optional for master)
  Serial.begin(2000000);  // start serial for output
  currentMillis = millis(); // Initial time
  for (int actuator = 0; actuator < NUM_ACTUATORS; actuator++) {
    writeI2C(pressureRegulatorAddresses[actuator], INDEX_OPERATION_MODE, controlMode); // Send pic firmware mode to the actuator
    writeI2C(pressureRegulatorAddresses[actuator], INDEX_HALF_BAND, halfBand); // Send inHalfBand to the actuator
    writeI2C(pressureRegulatorAddresses[actuator], INDEX_ONLY_SEND_PRESSURE, onlySendPressure); // Send "don't only send pressure" to the actuator
  }
}

void loop() {
  // Periodically, change command
  if (millis() > currentMillis + commandMillis) {
    currentMillis = millis();
    iterState++;
    changeState = true;
  }

  // Write to and read from slaves
  for (int actuator = 0; actuator < NUM_ACTUATORS; actuator++) {
    readPressureRegulator(pressureRegulatorAddresses[actuator], filteredValues[actuator], expConst, values[actuator]); // manual is PIC waits for you to tell it with arduino or whatever command to open or close. automatic: you tell it pressure, it gets there. Manual: you can control each valve independently (in this test code)  

    // Change command if it is a "command cycle"
    if (changeState) {
      if (controlMode == AUTOMATIC) {
        command = 3 * (iterState % 3); // [psi]
        float commandVolt = psiToVolt(command);
        commandToSend = voltToTenBit(commandVolt) >> 2; // Only send high byte (high 8 bits)
        Serial.println(commandToSend); 
        writeI2C(pressureRegulatorAddresses[actuator], INDEX_SETPOINT_HIGH_BYTE, commandToSend); // Send command to the actuator
      }

      if (controlMode == MANUAL) {
        command = 2 - iterState % 3; // Only valid states are 0,1,2. PIC will 'modulo' on its own.
        writeI2C(pressureRegulatorAddresses[actuator], INDEX_DESIRED_STATE, command); // Send command to the actuator // COMMAND is Open close or hold in manual mode. In automatic mode command is PSI 
      }
    }
  }

  finishCycle();
}

void finishCycle() {
  changeState = false;
  delay(cycleMillis);
  Serial.print(command);
  Serial.print("\t");
  Serial.println("");
  for (int actuator = 0; actuator < NUM_ACTUATORS; actuator++) {
    Serial.print(values[actuator]); Serial.print("\t");
  }
}

// Communicate with Pressure Regulator **************************************

void readPressureRegulator(const int &inAddress, float &inFiltered, const float &inA, float &inReading) {
  // Read the pressure regulator's air-pressure sensor, and filter it. This function specifically reads pressure, not a generic memory address.

  // Tell the PIC which address to read from, if we are not in "onlySendPressure" mode
  if (!onlySendPressure) {
    Wire.beginTransmission(inAddress); //Prepare internal variables
    Wire.write(INDEX_PRESSURE_SENSOR_HIGH_BYTE);        // write memory location to buffer
    Wire.endTransmission();    // transmit
  }

  // Request data
  Wire.requestFrom(inAddress, 2); byte b1_local = Wire.read(); byte b2_local = Wire.read();
  inReading = ((float)b1_local * 256 + (float)b2_local) / pow(2, 6); // Only keep 10 high bits. Convert to voltage
  inReading = tenBitToVolt(inReading);
  inReading = voltToPsi(inReading);
  inFiltered = (inA * inFiltered + (1 - inA) * inReading); //filter the noise, exponential filter
}

void writeI2C(int inAddress, int inIndex, int inValue) {
  Wire.beginTransmission(inAddress); //Prepare internal variables
  Wire.write(inIndex);        // write memory locaiton to buffer
  Wire.write(inValue);        // write value to buffer
  Wire.endTransmission();    // transmit
}
// End communicate with Pressure Regulator **************************************

// Unit conversions  **************************************

float tenBitToVolt(float inTenBit) {
  // Convert a 10-bit "5V source ADC reading" to voltage.
  // Specifically, our PIC has a supply voltage of 5V and uses a 10 bit ADC.
  float volts = inTenBit * 5 / pow(2, 10);
  return volts;
}

unsigned long voltToTenBit(float inVolts) {
  // Convert from voltage to a ten bit "5V source ADC reading", scaled as 2^10 distinct values over 5 volts.
  // Specifically, our PIC has a supply voltage of 5V and uses a 10 bit ADC.
  unsigned long tenBit = inVolts * pow(2, 10) / 5;
  return tenBit;
}
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

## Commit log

2018-11-05 data communcation between nodes, still need to do data saving and arduino
2018-11-07 tested communication to arduino, have images saving with proper timing, create directories for data saving
2018-11-14 final working arduino side low level electronics control working
2018-11-18 lots of work today
    [csvSave.csv]
2018-11-20 saving the matlab script just in case
2018-11-29 arduino correct
2018-11-29 reorganized and added applicable files for the project
    [Arduino Communication.xlsx, Assem1.SLDASM, Assem1_no_brackets.SLDASM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]
